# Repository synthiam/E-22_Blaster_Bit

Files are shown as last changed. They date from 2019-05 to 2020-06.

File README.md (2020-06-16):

# E-22 Blaster Bit

**Project Status:** Ready to manufacture

If you are new to GitHub and would like to create a derivative of this project, please have a look at GitHub instructions to [fork a repo](https://help.github.com/en/articles/fork-a-repo)

## Description

Out of our passion to solve the issue of time waste in the robot creation process, ARC was born. The ARC software platform reduces the time it takes to get from idea to implementation. Since 2011 we have been listening to the challenges robot builders encounter and continue to provide them with an ever expanding toolbox of solutions. Join us on this journey!

We didn't stop at the software, we also made time saving hardware solutions. This Blaster Bit reference design is one of them. The Blaster Bit connects to the E-21 Neopixel Blaster. With ARC you can create colorful Blaster bit animations! A unique feature of the blaster bit is that it has a 5V regulator on-board so that it can be powered by, or protected from, higher voltages.  We want to share these files with you so you can create your own version for your community and customers to enjoy!

**Features:** 
- Output Connector to chain Neopixels using one channel
- 80 Blaster bits can be used per NeoPixel Blaster channel
- 5V tolerant data pin
- Can display 1 of 16 million different colors
- ARC Skill available
- Voltage requirement: 6-24VDC (7.4V Typical)
- Current draw: WS2812B off - 0.5mA, WS2812B white - 39mA
- Dimensions: 16.3(W) x 18.3(L) x 10.4(H) (mm)
- Weight: 1g

**Major components:** 
- WS2812B Addressable RGB LED
- AP2204K-5.0TRG1 5V Linear voltage regulator

**Manufacturing notes:** 
1. Manufacturer: Single side placement and soldering of SMT components
2. Manufacturer: Single Side soldering of THT components

**Note:** This reference design requires the E-21 NeoPixel Blaster: https://github.com/synthiam/E-21_Neopixel_Blaster

## Contents

[**Documentation:**](https://github.com/synthiam/E-22_Blaster_Bit/tree/master/E-22%20Documentation) Schematic PDF, Datasheet PDF, BOM, Assembly Instructions, Test Procedures

[**Hardware:**](https://github.com/synthiam/E-22_Blaster_Bit/tree/master/E-22%20Hardware) Altium PCB design File, Altium SCH Design File, Gerbers

*Altium Libraries are also available <a href="https://github.com/synthiam/Synthiam_Altium_Librairies">here</a>*

## Photos

<p align="left">


</p>

## Roll Out Video

This Roll-out Video includes:

1. Feature set 
2. Hook-up guide 
3. Using Synthiam EZ-Builder Software Behavior Control
4. Custom firmware location
5. Schematic overview
6. Bill of Materials (BOM) overview
7. Assembly instructions 

Link: https://youtu.be/iWZ4e5sMYgQ



## ARC Skill

The ARC Neopixel Blaster Skill makes it easy to control the Blaster Bit. The LED colors can be chained and activated with a simple code segment. 

Link: https://synthiam.com/Software/Manual/Neopixel-Blaster-16172



## Contact

For profit use of these files requires written consent. Contact partners@synthiam.com. For everyone else, party on!

For support check out our Synthiam Community: https://synthiam.com/Community

## License

This project is released under the following license:

**Hardware:** Creative Commons Plus Attribution-NonCommercial 4.0 International (CC+ BY-NC 4.0)

Please see [LICENSE.md](https://github.com/synthiam/E-22_Blaster_Bit/blob/master/LICENSE.md) for license details.



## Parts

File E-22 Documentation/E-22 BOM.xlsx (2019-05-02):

Qty | Description | Manufacturer Part No. | Alternative | Designator | Custom Information | Link
E-22 Blaster Bit
1 | 2 layer, Blue soldermask, White silkscreen, ENIG | Blaster Bit Board |  | PCB
1 | 5V Linear voltage regulator (150mA) upto 24V SOT25 | AP2204K-5.0TRG1 |  | VR1 |  | https://www.digikey.ca/product-detail/en/diodes-incorporated/AP2204K-5.0TRG1/AP2204K-5.0TRG1DICT-ND/4505289
1 | 0.1uF 16V 0805 Ceramic Capacitor | CL21F104ZBCNNNC | C0805C104K5RAC | C1
2 | 10uF 25V 0805 Ceramic Capacitor | CL21A106KAFN3NE |  | C2, C3
1 | 40-pin Black Male 0.1” pitch header | FIT0084-B | 00834 | P2 | This header needs to be broken down into 1 x 3-pin | http://www.4uconnector.com/online/SearchPro.asp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
1 | Addressable RGB LED | WS2812B |  | U2 |  | https://www.alibaba.com/product-detail/SK6812B-WS2812B-5050-RGB-Packing-LED_60329442470.html
1 | 3 position 2.0mm pitch JST-PH header | B3B-PH-K-S(LF)(SN) |  | P1 |  | https://www.digikey.ca/product-detail/en/jst-sales-america-inc/B3B-PH-K-S-LF-SN/455-1705-ND/926612

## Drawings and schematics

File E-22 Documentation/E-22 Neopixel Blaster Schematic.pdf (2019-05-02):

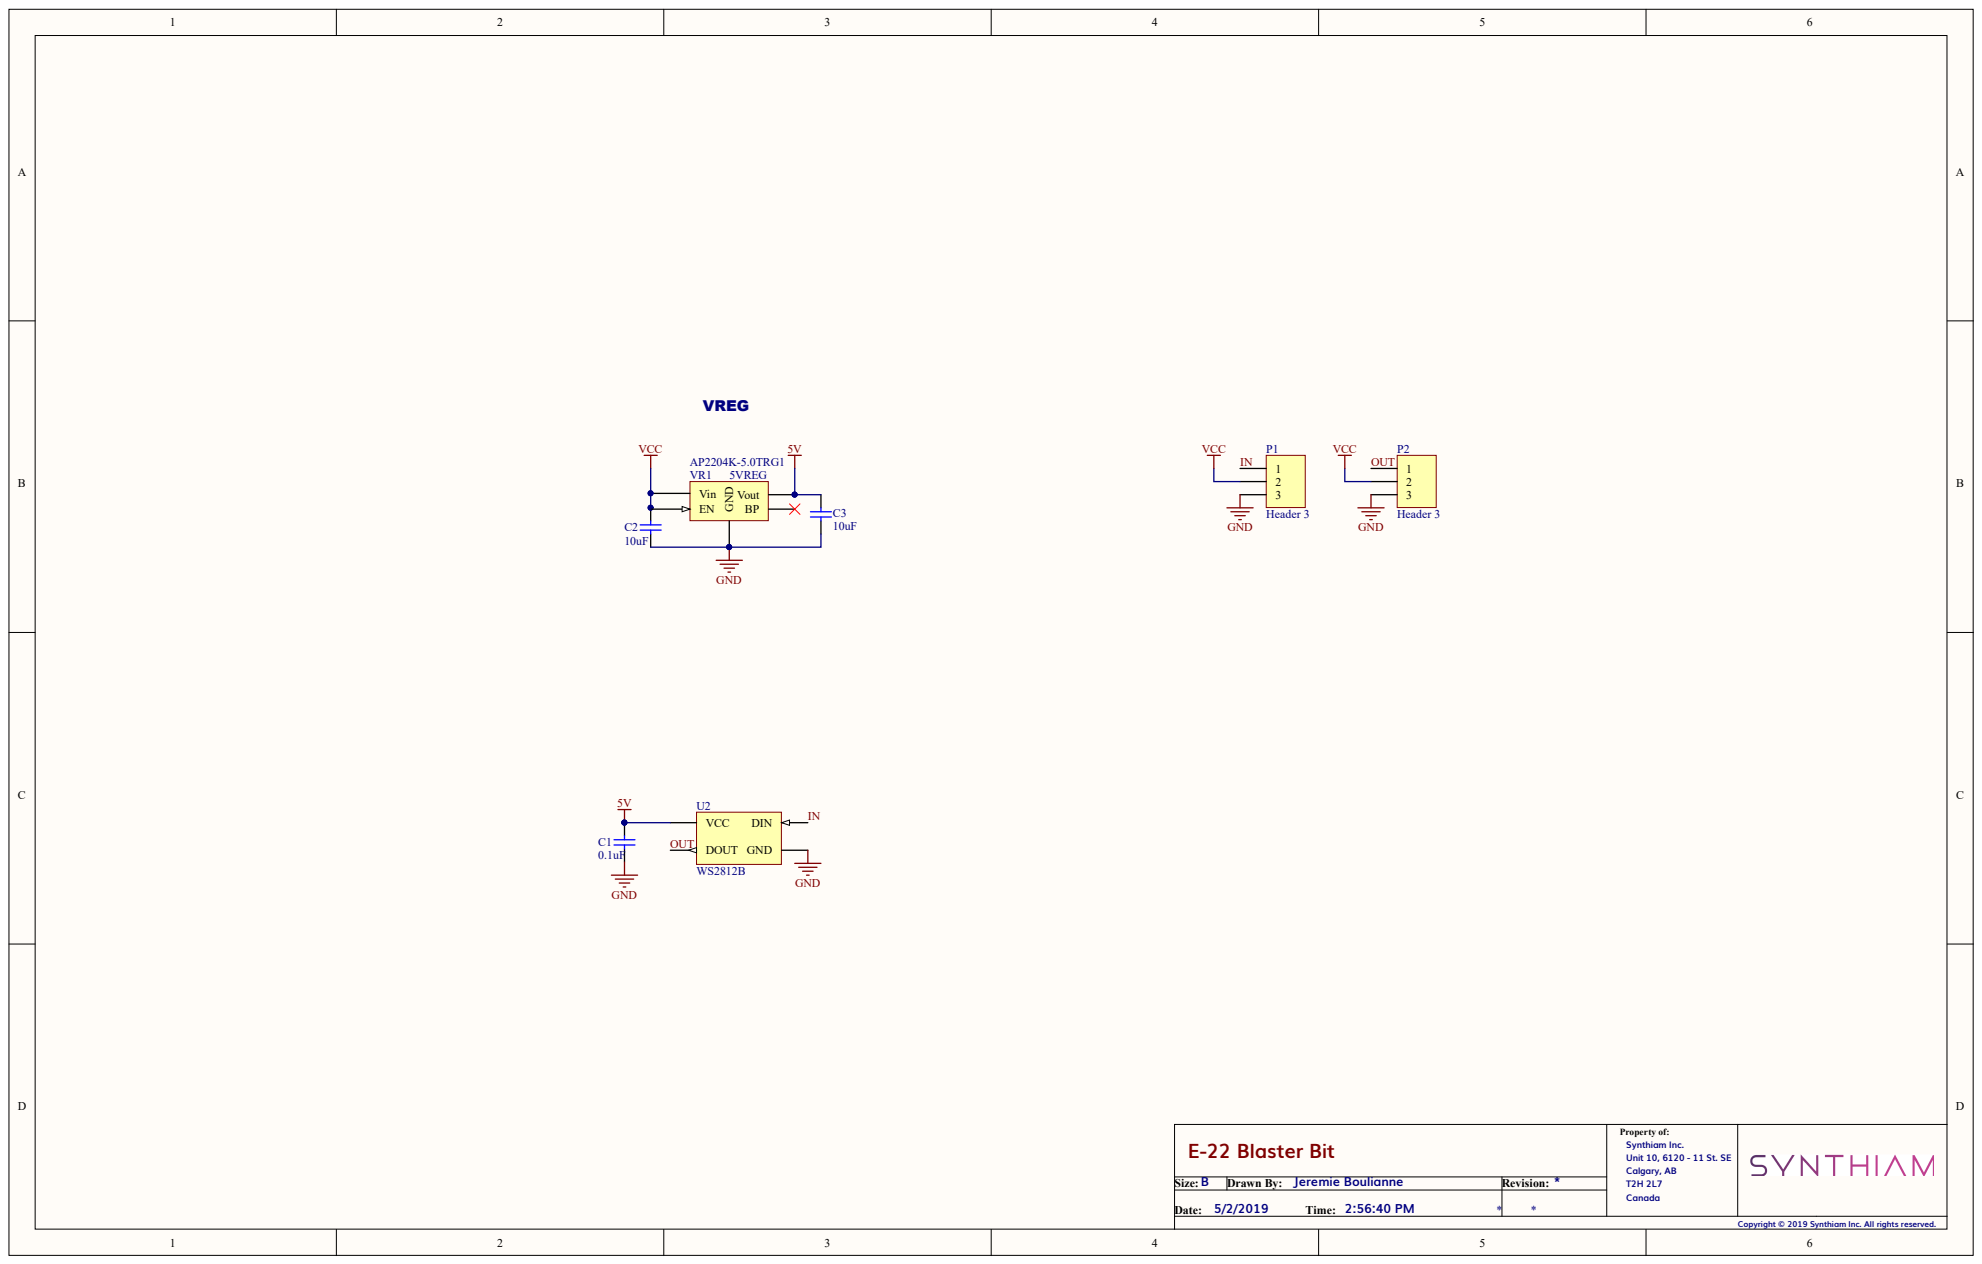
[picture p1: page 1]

E-22 Blaster Bit | Property of: Synthiam Inc. Unit 10, 6120 - 11 St. SE Calgary, AB T2H 2L7 Canada

B Size: | Jeremie Boulianne Drawn By: | * Revision:

5/2/2019 2:56:40 PM Date: Time: | | * *

Copyright © 2019 Synthiam Inc. All rights reserved.

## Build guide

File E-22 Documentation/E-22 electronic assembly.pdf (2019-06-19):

# Assembly Instructions

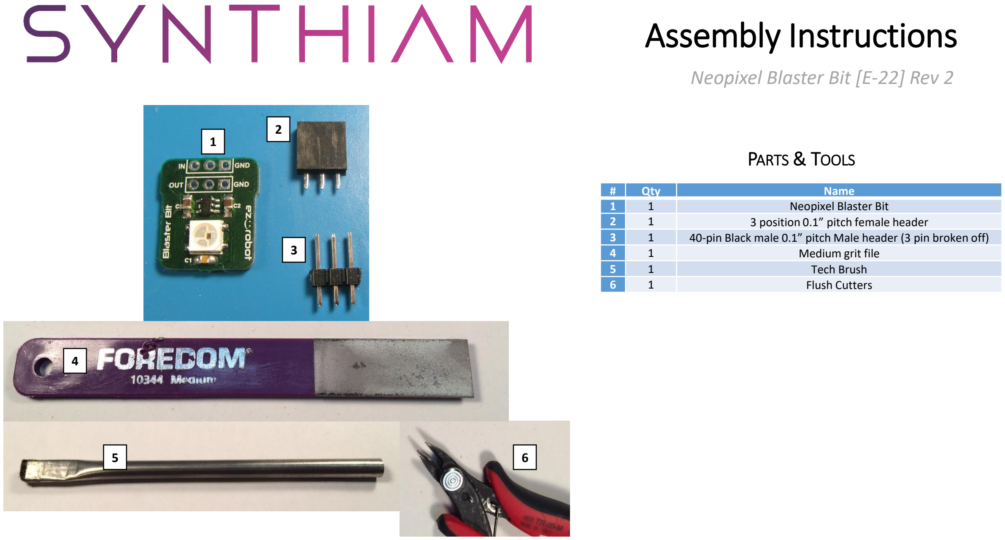
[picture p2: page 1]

# | Qty | Name

1 | 1 | Neopixel Blaster Bit
2 | 1 | 3 position 0.1” pitch female header
3 | 1 | 40-pin Black male 0.1” pitch Male header (3 pin broken off)
4 | 1 | Medium grit file
5 | 1 | Tech Brush
6 | 1 | Flush Cutters

Neopixel Blaster Bit [E-22] Rev 2

PARTS & TOOLS

1

5

2

6

4

3

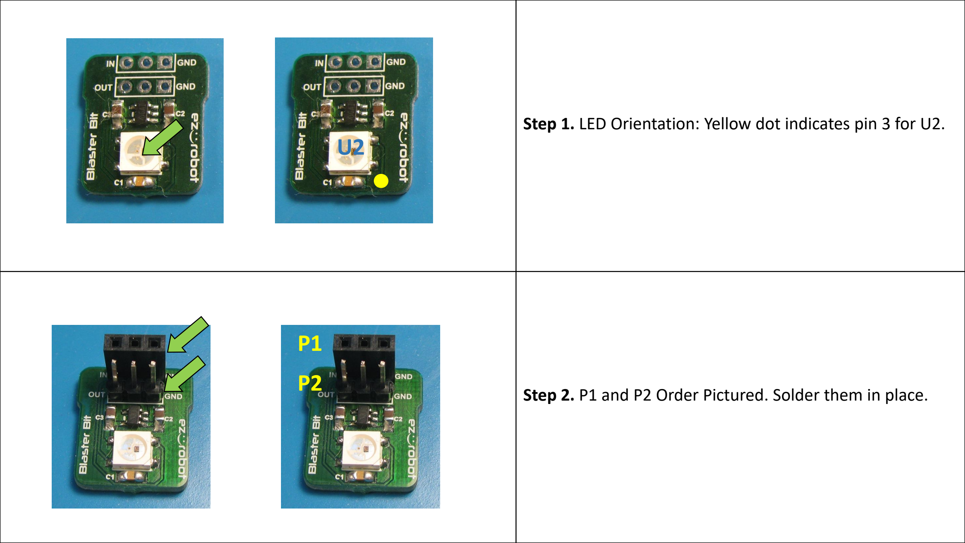
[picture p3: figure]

Step 1. LED Orientation: Yellow dot indicates pin 3 for U2.
Step 2. P1 and P2 Order Pictured. Solder them in place.

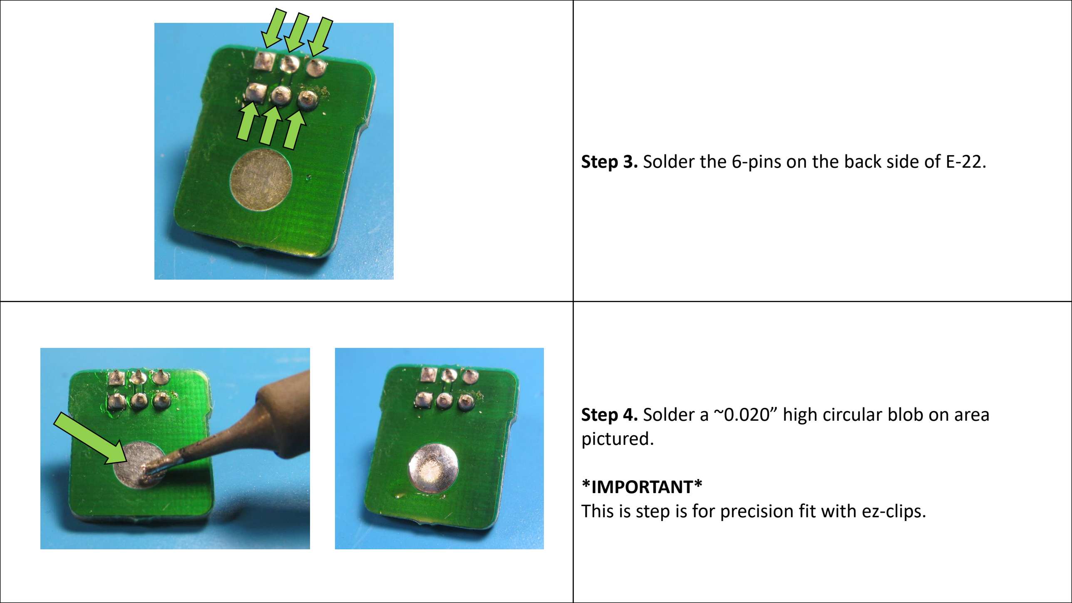
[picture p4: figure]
pictured.; *IMPORTANT*

Step 3. Solder the 6-pins on the back side of E-22.
Step 4. Solder a ~0.020” high circular blob on area

This is step is for precision fit with ez-clips.

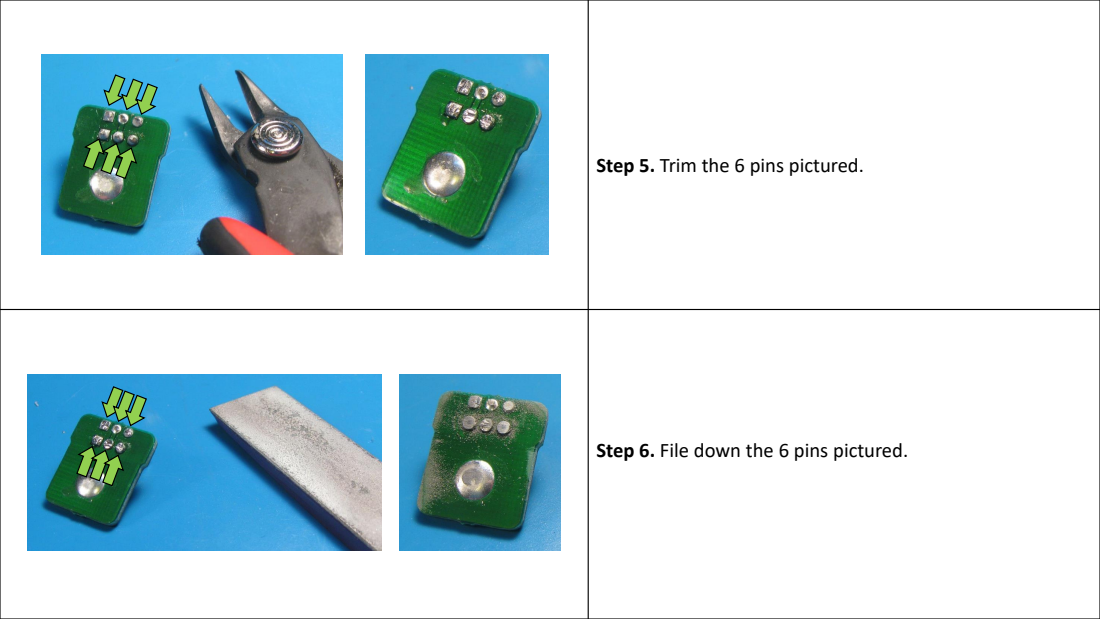
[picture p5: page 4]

Step 5. Trim the 6 pins pictured.

Step 6. File down the 6 pins pictured.

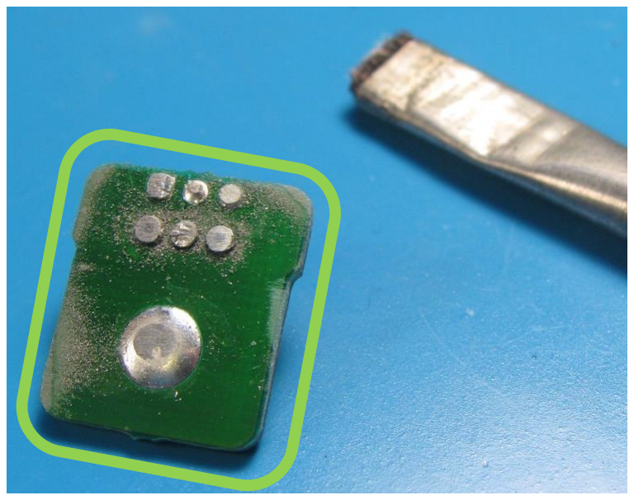
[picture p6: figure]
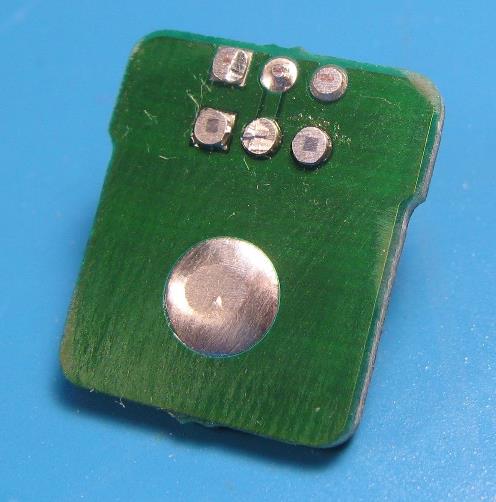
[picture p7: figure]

Step 7. Clean the entire back of the E-22 PCB with a tech brushrush

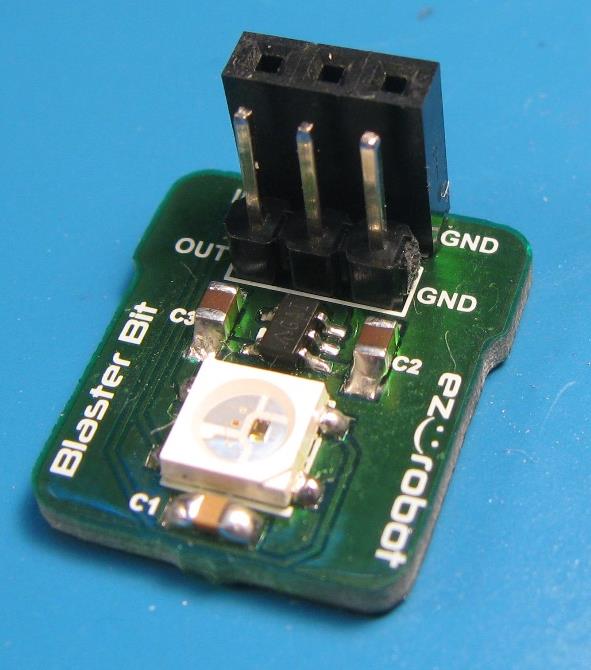
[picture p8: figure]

The E-22 Neopixel Blaster Bit is now complete.

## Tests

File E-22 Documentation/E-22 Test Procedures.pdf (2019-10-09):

# E-22 Test Procedures

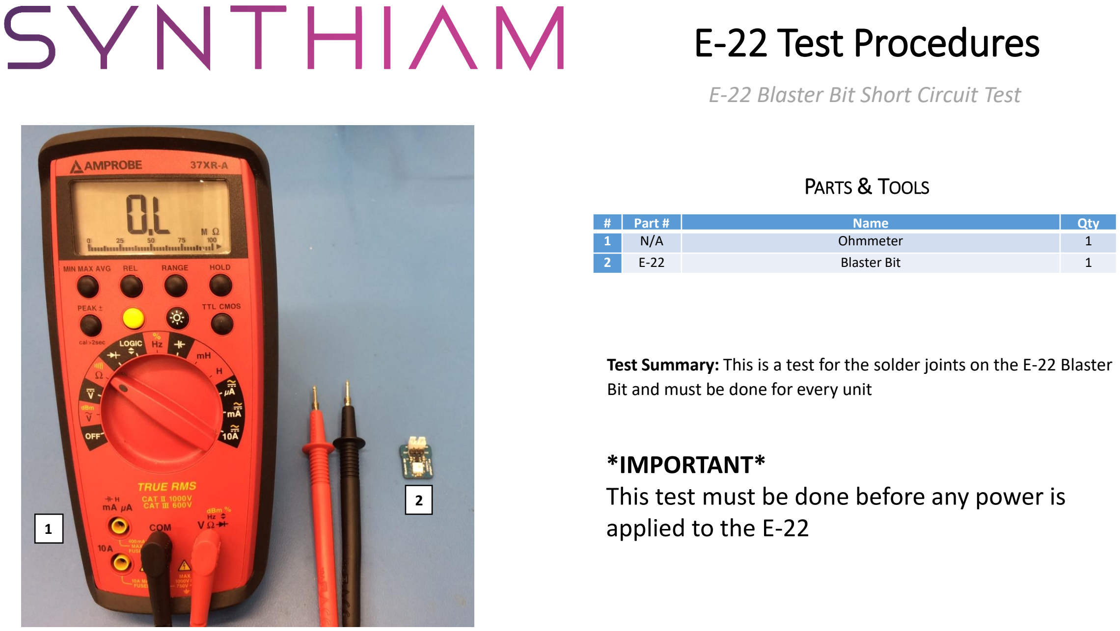
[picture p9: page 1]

# | Part # | Name | Qty

1 | N/A | Ohmmeter | 1
2 | E-22 | Blaster Bit | 1

E-22 Blaster Bit Short Circuit Test

PARTS & TOOLS

Test Summary: This is a test for the solder joints on the E-22 Blaster Bit and must be done for every unit

*IMPORTANT*
This test must be done before any power is

### 1 applied to the E-22

2

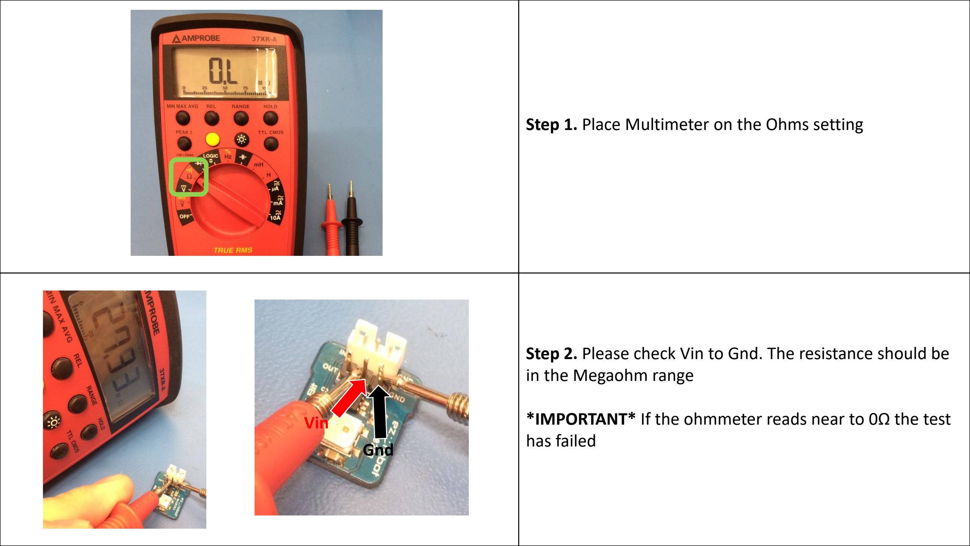
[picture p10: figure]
in the Megaohm range; has failed; Vin; Gnd

Step 1. Place Multimeter on the Ohms setting
Step 2. Please check Vin to Gnd. The resistance should be

*IMPORTANT* If the ohmmeter reads near to 0Ω the test

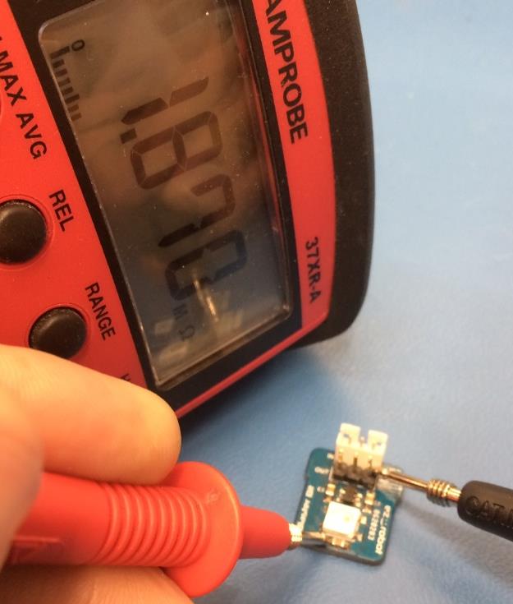
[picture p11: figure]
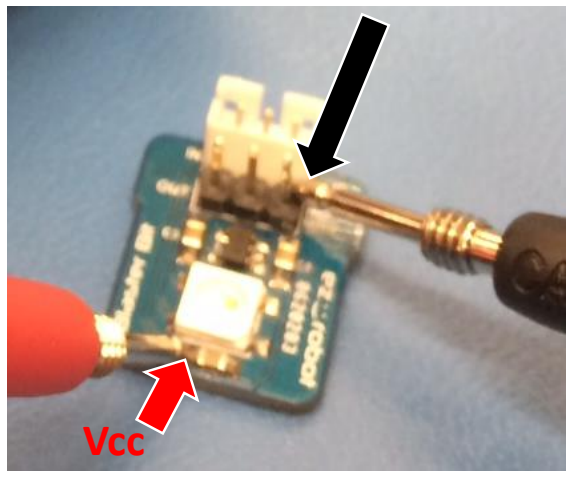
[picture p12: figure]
Vcc

Step 3. Please check Vcc to Gnd. The resistance should be in the Megaohm range. The E-22 Short Circuit Test is now complete

*IMPORTANT* If the ohmmeter reads near to 0Ω the test has failed.

Gnd

# E-22 Test Procedures

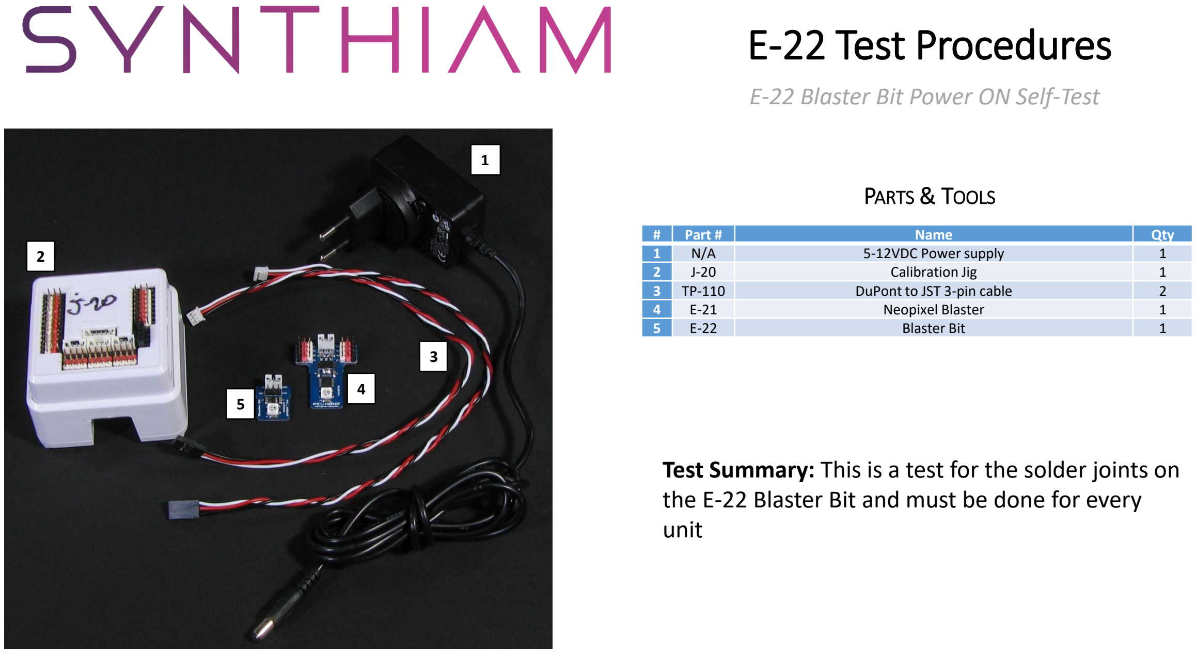
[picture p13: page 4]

# | Part # | Name | Qty

1 | N/A | 5-12VDC Power supply | 1
2 | J-20 | Calibration Jig | 1
3 | TP-110 | DuPont to JST 3-pin cable | 2
4 | E-21 | Neopixel Blaster | 1
5 | E-22 | Blaster Bit | 1

E-22 Blaster Bit Power ON Self-Test

PARTS & TOOLS

1

2

3

4

Test Summary: This is a test for the solder joints on the E-22 Blaster Bit and must be done for every unit

5

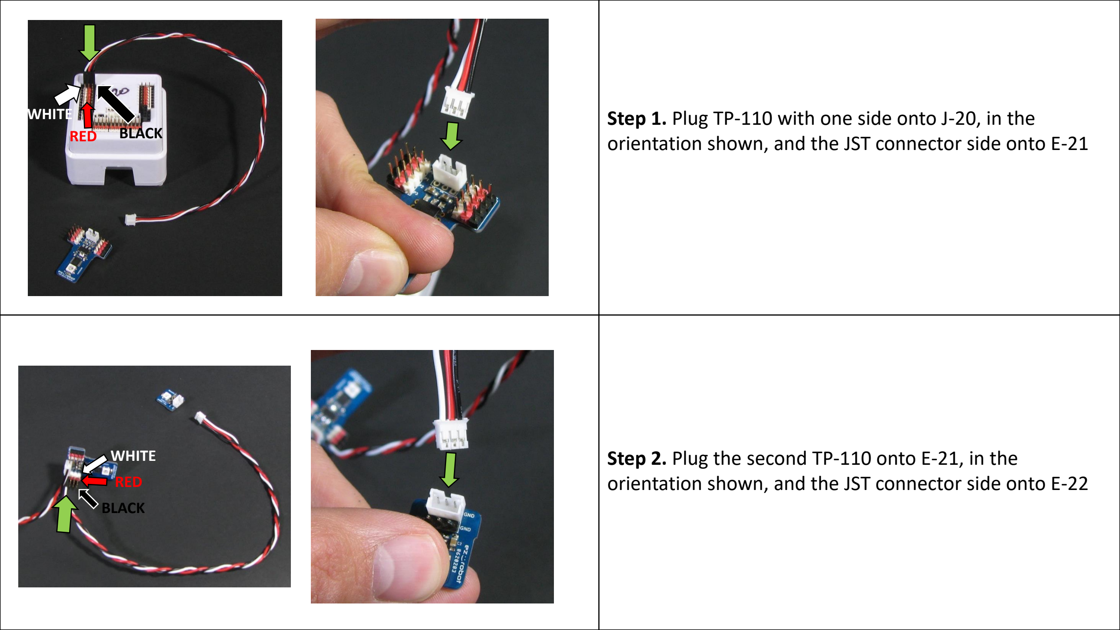
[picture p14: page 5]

Step 1. Plug TP-110 with one side onto J-20, in the orientation shown, and the JST connector side onto E-21
Step 2. Plug the second TP-110 onto E-21, in the orientation shown, and the JST connector side onto E-22

WHITE
RED BLACK

WHITE
RED
BLACK

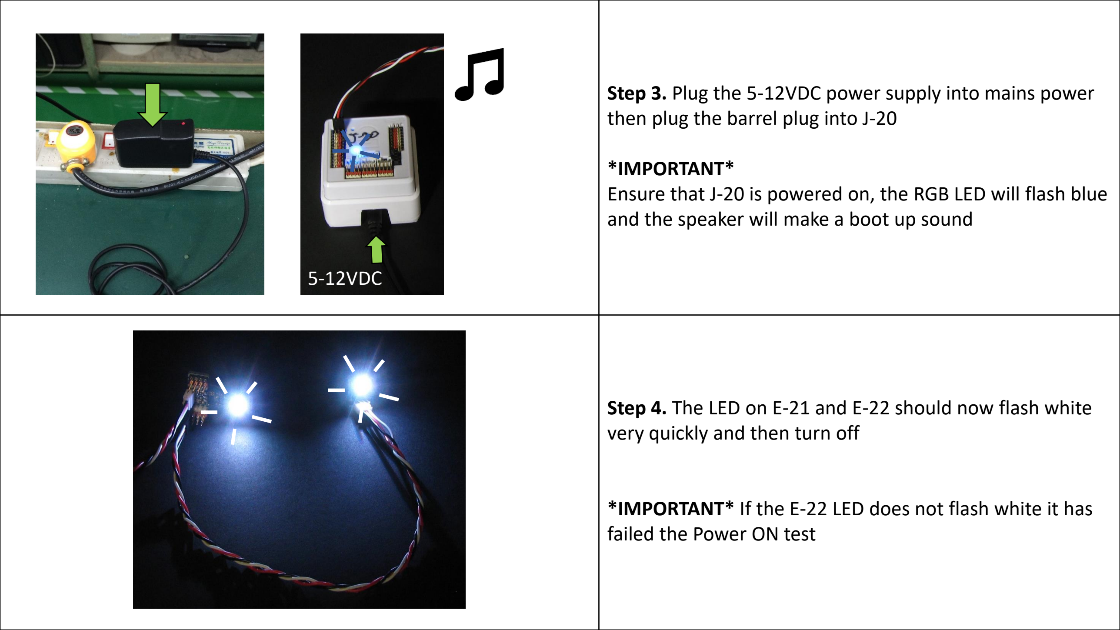
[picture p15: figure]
then plug the barrel plug into J-20; *IMPORTANT*; very quickly and then turn off; failed the Power ON test; 5-12VDC

Step 3. Plug the 5-12VDC power supply into mains power

Ensure that J-20 is powered on, the RGB LED will flash blue and the speaker will make a boot up sound

Step 4. The LED on E-21 and E-22 should now flash white

*IMPORTANT* If the E-22 LED does not flash white it has

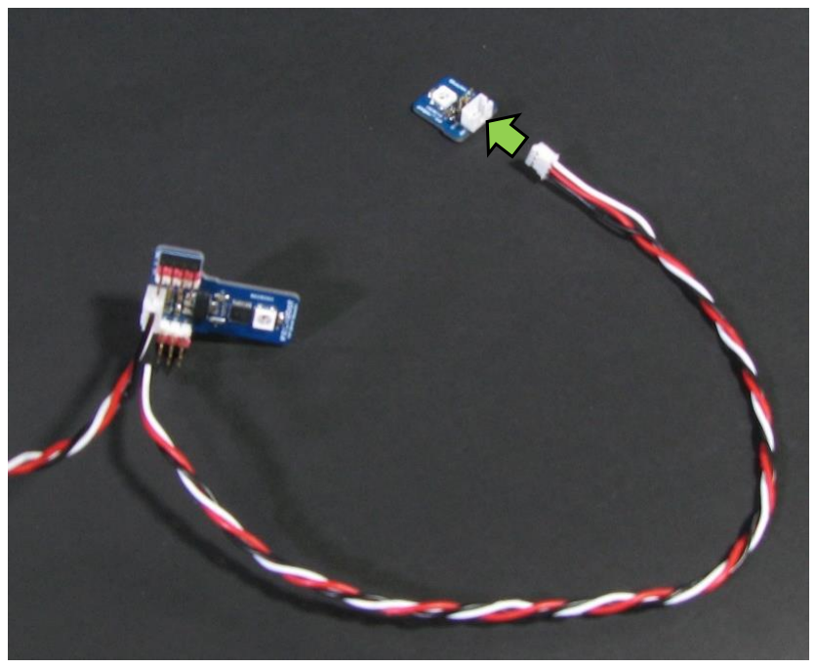
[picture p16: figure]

Step 5. Remove E-22 from TP-110. The E-22 Power ON Self-Test is now complete
